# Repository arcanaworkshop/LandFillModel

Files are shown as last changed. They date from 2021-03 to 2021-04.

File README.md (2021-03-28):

# README Landfill Model Guide

Create by George Spearing for Arcana Workshop
March 2020

## Purpose

The lanfill model is run by an Arduino Nano with a breakout board to control audio track files. The audio track files live on the microSD card in the breakout board. Formmating for files are shown below.

## Audio Track Naming

The audio tracks are labeled using the scheme "TRACK000.wav" where "000" is the track identifier. These track numbers correspond to the buttons which light up specific sections.

## Track Numbering

- "000" Electric Power Plant
- "001" Empty - Not Used
- "002" Ground Water
- "003" Ground Liner
- "004" Leache Runoff
- "005" Gas Collection
- "006" Garbage Layer
- "007" Ground (Surface Layer)

## Track Formatting

The Arduino uses the TMRpcm library to play audio track from a microSD card. The full documentation for this library can be found at [https://github.com/TMRh20/TMRpcm/wiki](https://github.com/TMRh20/TMRpcm/wiki).

In summary, the tracks should be formatted as follows:

- Mono track
- 32000Hz (22050, 1600, 11025 also work)
- WAV, Unsigned 8 bit PCM

## Programming

I hope this doesn't need to be reprogrammed. There are two nano boards. 1 is the master and mainly controls all the leds. This is also the master to control the slave arduino file playing. The salve nano is a dedicated audio interpreter and player. This uses the micro SD card breakout. To program the slave nano, the SD car must NOT be connected. the MISO/MISI connections with the usbtiny during programming fail the upload. There is a switch on the circuit board that disables the SD card interface. Turn this off when progrmaming. DON'T FORGET TO TURN BACK ON ONCE DONE.

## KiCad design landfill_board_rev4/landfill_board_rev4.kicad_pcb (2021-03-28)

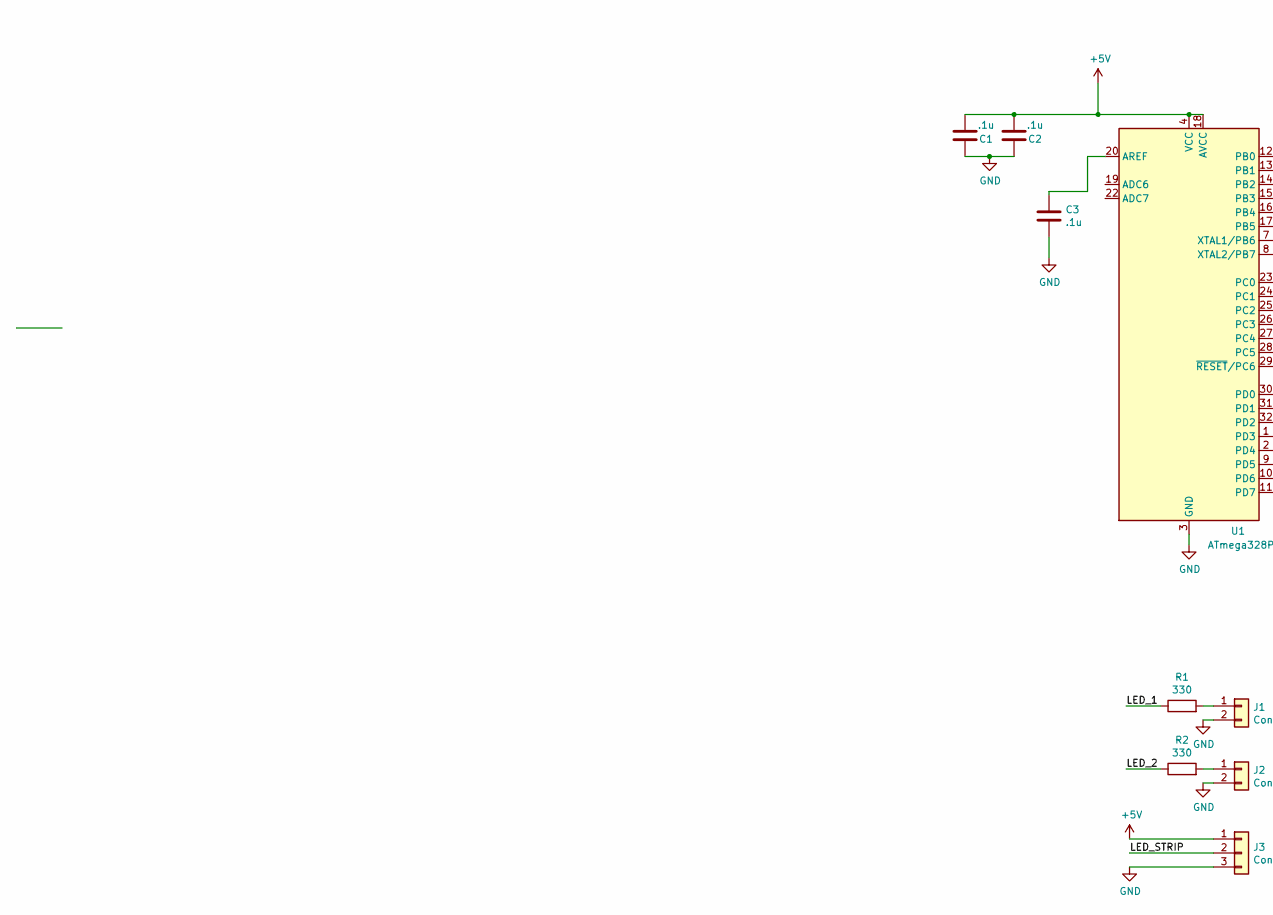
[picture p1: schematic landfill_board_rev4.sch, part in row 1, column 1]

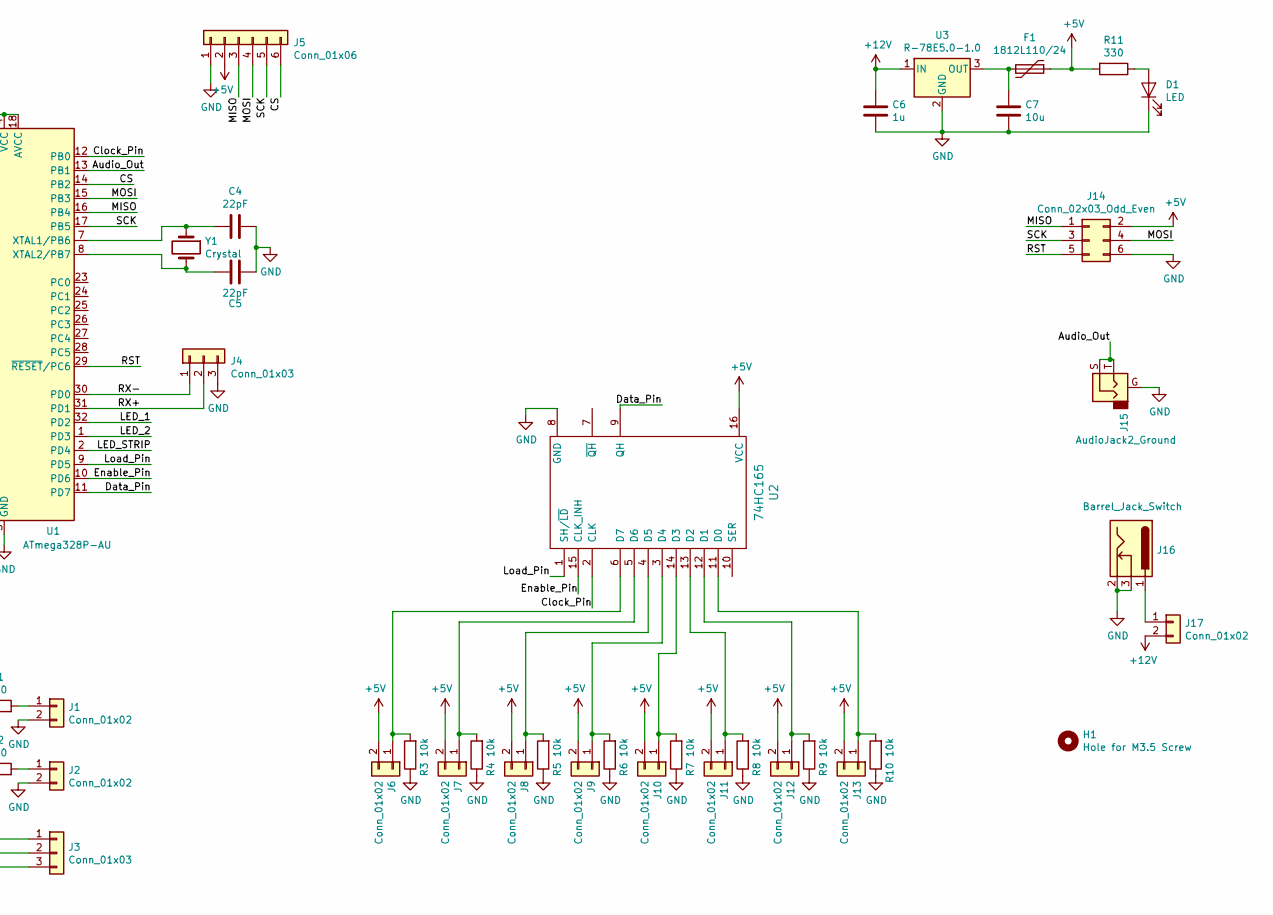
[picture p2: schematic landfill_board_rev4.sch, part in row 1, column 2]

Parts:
C1, C2, C3: .1u; C_0603_1608Metric_Pad1.05x0.95mm_HandSolder
C4, C5: 22pF; C_0603_1608Metric_Pad1.05x0.95mm_HandSolder
C6: 1u; C_0603_1608Metric_Pad1.05x0.95mm_HandSolder
C7: 10u; C_0603_1608Metric_Pad1.05x0.95mm_HandSolder
D1: LED; LED_0603_1608Metric_Pad1.05x0.95mm_HandSolder
F1: 1812L110/24; Fuse_1812_4532Metric_Pad1.30x3.40mm_HandSolder
H1: Hole for M3.5 Screw; MountingHole_3.5mm
J1, J2, J6, J7, J8, J9, J10, J11, J12, J13, J17: Conn_01x02; JST_PH_B2B-PH-K_1x02_P2.00mm_Vertical
J3: Conn_01x03; JST_PH_B3B-PH-K_1x03_P2.00mm_Vertical
J4: Conn_01x03; PinSocket_1x03_P2.54mm_Vertical
J5: Conn_01x06; PinHeader_1x06_P2.54mm_Vertical
J14: Conn_02x03_Odd_Even; PinHeader_2x03_P2.54mm_Vertical
J15: AudioJack2_Ground; Jack_3.5mm_CUI_SJ-3523-SMT_Horizontal
J16: Barrel_Jack_Switch; BarrelJack_CUI_PJ-036AH-SMT_Horizontal
R1, R2, R11: 330; R_0603_1608Metric_Pad1.05x0.95mm_HandSolder
R3, R4, R5, R6, R7, R8, R9, R10: 10k; R_0603_1608Metric_Pad1.05x0.95mm_HandSolder
U1: ATmega328P-AU; TQFP-32_7x7mm_P0.8mm
U2: 74HC165; SOIC-16_3.9x9.9mm_P1.27mm
U3: R-78E5.0-1.0; Converter_DCDC_RECOM_R-78E-0.5_THT
Y1: Crystal; Crystal_HC49-U_Vertical

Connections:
+5V: C1.2, C2.2, F1.1, J3.1, J5.2, J6.2, J7.2, J8.2, J9.2, J10.2, J11.2, J12.2, J13.2, J14.2, R11.2, U1.4 (VCC), U1.6 (VCC), U1.18 (AVCC), U2.16 (VCC)
+12V: C6.1, J17.2, U3.1 (IN)
/Audio_Out: J15.S, J15.T, U1.13 (PB1)
/CS: J5.6, U1.14 (PB2)
/Clock_Pin: U1.12 (PB0), U2.2 (CLK)
/Data_Pin: U1.11 (PD7), U2.9 (QH)
/Enable_Pin: U1.10 (PD6), U2.15 (CLK_INH)
/LED_1: R1.1, U1.32 (PD2)
/LED_2: R2.1, U1.1 (PD3)
/LED_STRIP: J3.2, U1.2 (PD4)
/Load_Pin: U1.9 (PD5), U2.1 (SH/~LD)
/MISO: J5.3, J14.1, U1.16 (PB4)
/MOSI: J5.4, J14.4, U1.15 (PB3)
/RST: J14.5, U1.29 (~RESET~/PC6)
/RX+: J4.2, U1.31 (PD1)
/RX-: J4.1, U1.30 (PD0)
/SCK: J5.5, J14.3, U1.17 (PB5)
GND: C1.1, C2.1, C3.2, C4.1, C5.1, C6.2, C7.2, D1.1 (K), J1.2, J2.2, J3.3, J4.3, J5.1, J14.6, J15.G, J16.2, J16.3, R3.1, R4.1, R5.1, R6.1, R7.1, R8.1, R9.1, R10.1, U1.3 (GND), U1.5 (GND), U1.21 (GND), U2.8 (GND), U3.2 (GND)
unnamed: C3.1, U1.20 (AREF)
unnamed: C4.2, U1.7 (XTAL1/PB6), Y1.1
unnamed: C5.2, U1.8 (XTAL2/PB7), Y1.2
unnamed: C7.1, F1.2, U3.3 (OUT)
unnamed: D1.2 (A), R11.1
unnamed: J1.1, R1.2
unnamed: J2.1, R2.2
unnamed: J6.1, R3.2, U2.6 (D7)
unnamed: J7.1, R4.2, U2.5 (D6)
unnamed: J8.1, R5.2, U2.4 (D5)
unnamed: J9.1, R6.2, U2.3 (D4)
unnamed: J10.1, R7.2, U2.14 (D3)
unnamed: J11.1, R8.2, U2.13 (D2)
unnamed: J12.1, R9.2, U2.12 (D1)
unnamed: J13.1, R10.2, U2.11 (D0)
unnamed: J16.1, J17.1

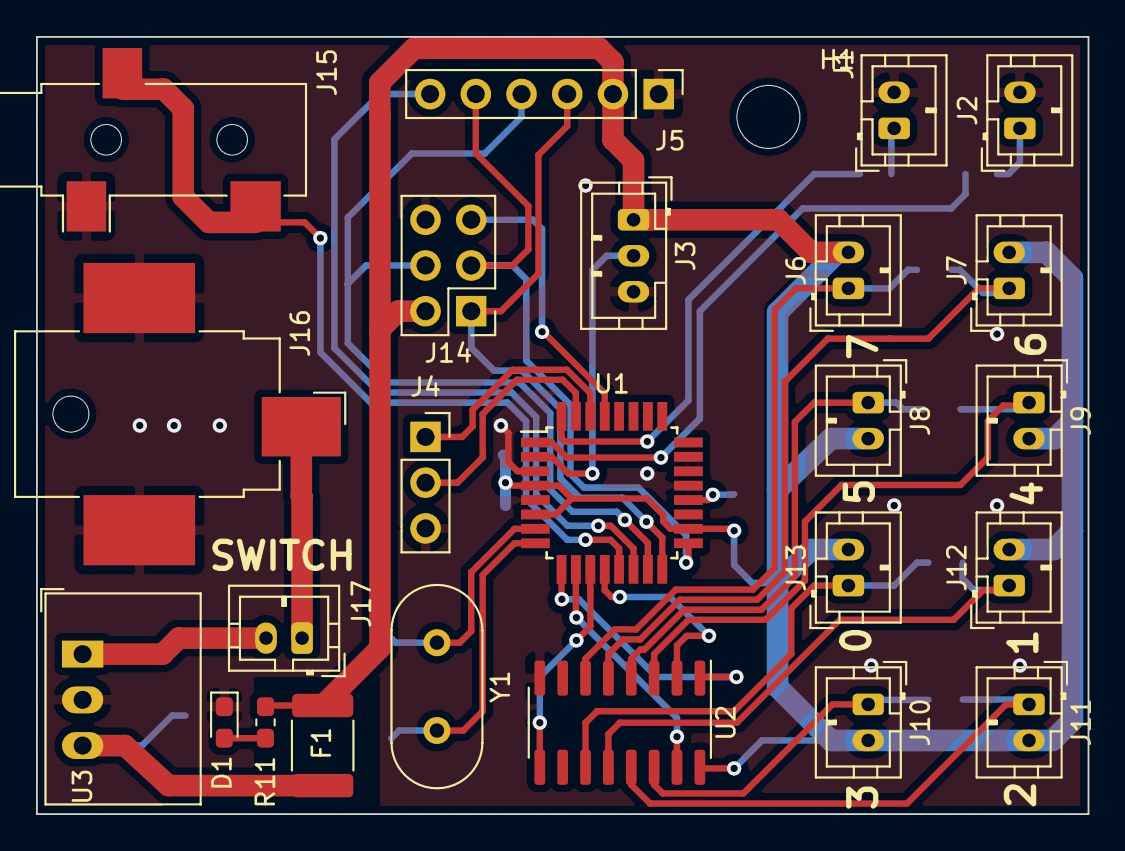
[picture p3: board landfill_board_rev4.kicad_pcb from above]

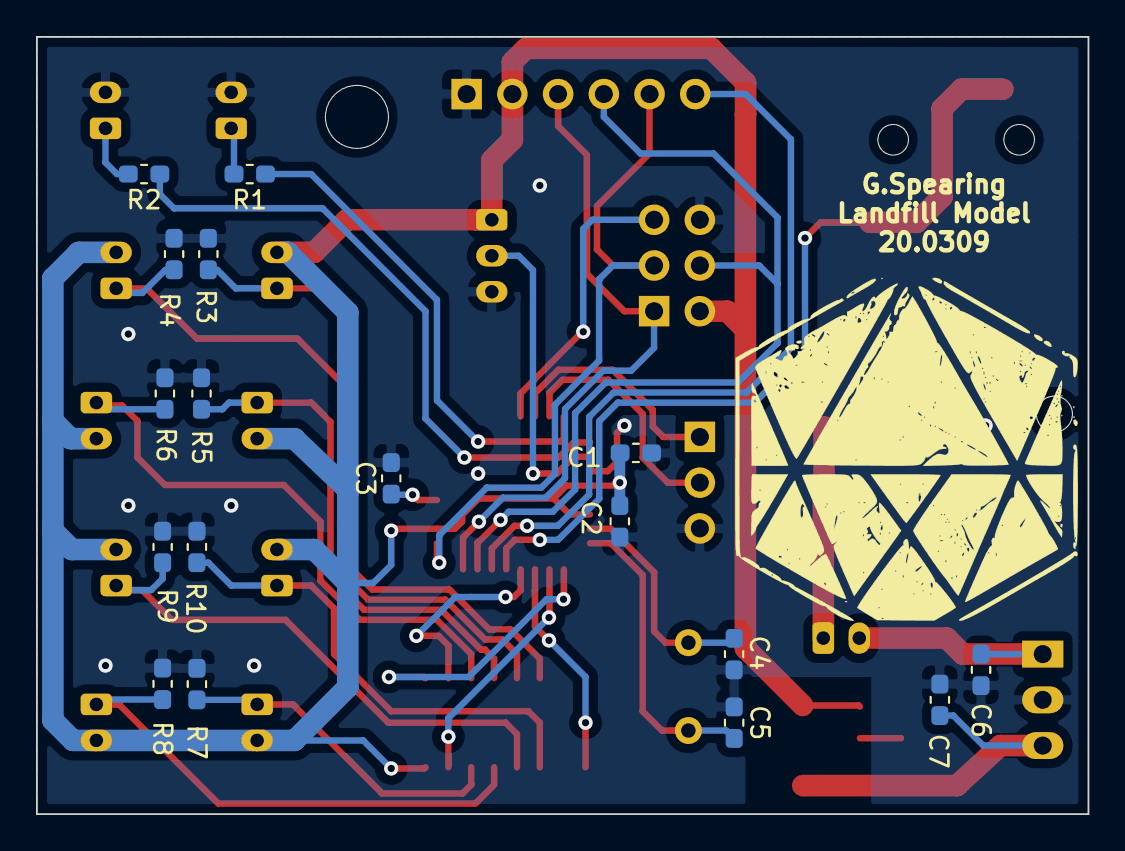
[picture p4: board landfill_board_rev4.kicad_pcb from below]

Board: 2 copper layers, 58.4 x 43.2 mm, 42 parts (17 on the bottom side), 34 nets.

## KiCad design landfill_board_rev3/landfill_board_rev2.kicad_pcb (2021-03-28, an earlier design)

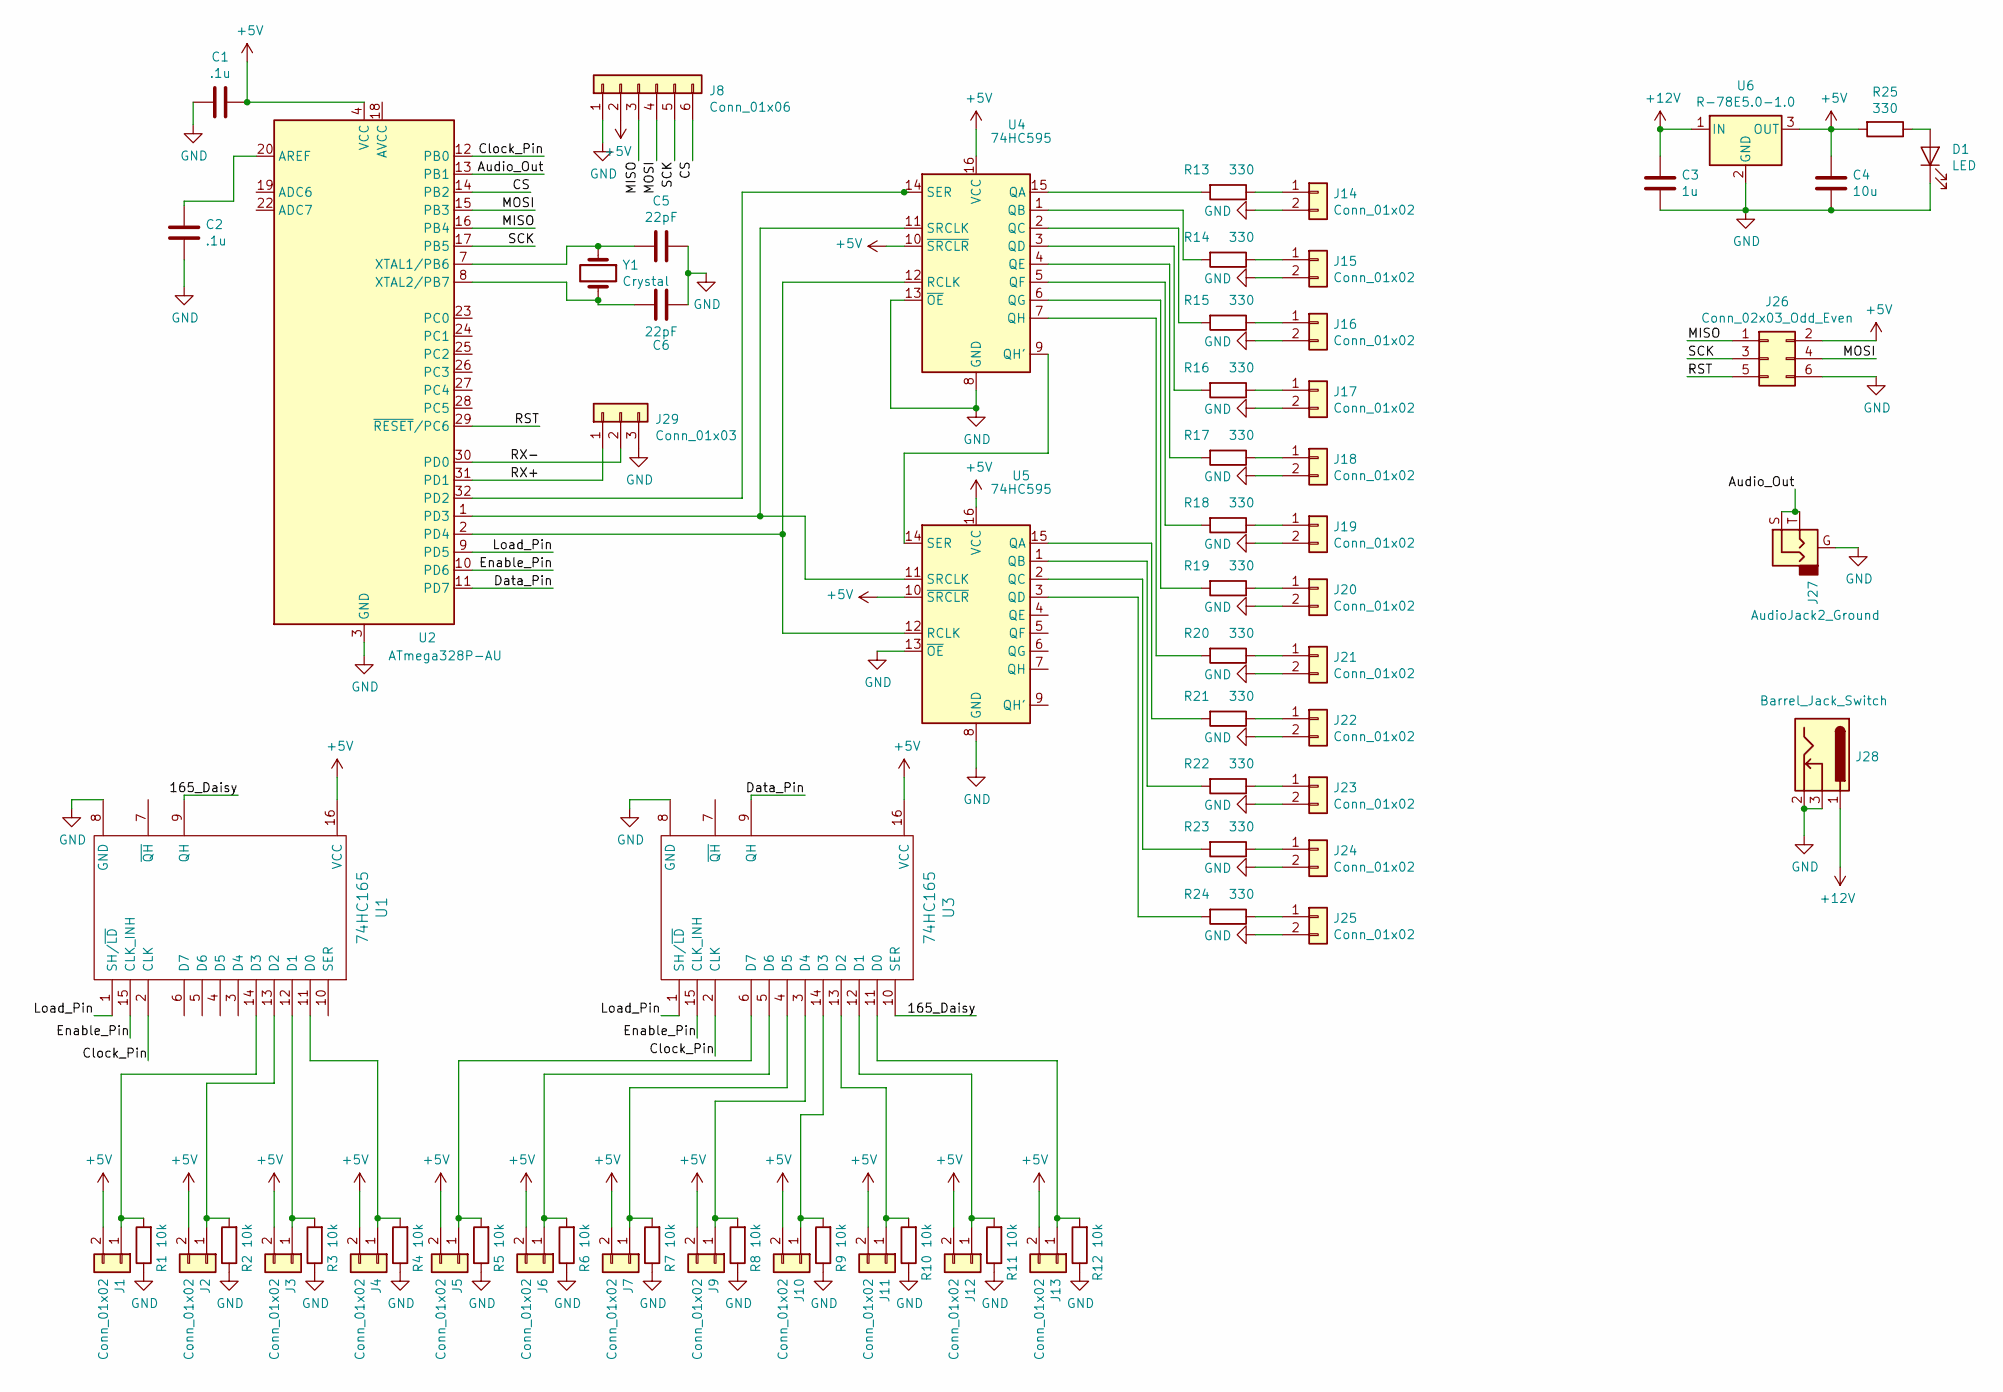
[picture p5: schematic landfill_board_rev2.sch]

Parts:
C1, C2: .1u; C_0603_1608Metric_Pad1.05x0.95mm_HandSolder
C3: 1u; C_0603_1608Metric_Pad1.05x0.95mm_HandSolder
C4: 10u; C_0603_1608Metric_Pad1.05x0.95mm_HandSolder
C5, C6: 22pF; C_0603_1608Metric_Pad1.05x0.95mm_HandSolder
D1: LED; LED_0603_1608Metric_Pad1.05x0.95mm_HandSolder
J1, J2, J3, J4, J5, J6, J7, J9, J10, J11, J12, J13, J14, J15, J16, J17, J18, J19, J20, J21, J22, J23, J24, J25: Conn_01x02; PinHeader_1x02_P2.00mm_Vertical
J8: Conn_01x06; PinHeader_1x06_P2.54mm_Vertical
J26: Conn_02x03_Odd_Even; PinHeader_2x03_P2.54mm_Vertical
J27: AudioJack2_Ground; Jack_3.5mm_CUI_SJ-3523-SMT_Horizontal
J28: Barrel_Jack_Switch; BarrelJack_CUI_PJ-036AH-SMT_Horizontal
J29: Conn_01x03; PinSocket_1x03_P2.54mm_Vertical
R1, R2, R3, R4, R5, R6, R7, R8, R9, R10, R11, R12: 10k; R_0603_1608Metric_Pad1.05x0.95mm_HandSolder
R13, R14, R15, R16, R17, R18, R19, R20, R21, R22, R23, R24, R25: 330; R_0603_1608Metric_Pad1.05x0.95mm_HandSolder
U1, U3: 74HC165; SOIC-16_3.9x9.9mm_P1.27mm
U2: ATmega328P-AU; TQFP-32_7x7mm_P0.8mm
U4, U5: 74HC595; SSOP-16_4.4x5.2mm_P0.65mm
U6: R-78E5.0-1.0; Converter_DCDC_RECOM_R-78E-0.5_THT
Y1: Crystal; Crystal_HC49-U_Vertical

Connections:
+5V: C1.1, C4.1, J1.2, J2.2, J3.2, J4.2, J5.2, J6.2, J7.2, J8.2, J9.2, J10.2, J11.2, J12.2, J13.2, J26.2, R25.2, U1.16 (VCC), U2.4 (VCC), U2.6 (VCC), U3.16 (VCC), U4.10 (~SRCLR), U4.16 (VCC), U5.10 (~SRCLR), U5.16 (VCC), U6.3 (OUT)
+12V: C3.1, J28.1, U6.1 (IN)
/165_Daisy: U1.9 (QH), U3.10 (SER)
/Audio_Out: J27.S, J27.T, U2.13 (PB1)
/CS: J8.6, U2.14 (PB2)
/Clock_Pin: U1.2 (CLK), U2.12 (PB0), U3.2 (CLK)
/Data_Pin: U2.11 (PD7), U3.9 (QH)
/Enable_Pin: U1.15 (CLK_INH), U2.10 (PD6), U3.15 (CLK_INH)
/Load_Pin: U1.1 (SH/~LD), U2.9 (PD5), U3.1 (SH/~LD)
/MISO: J8.3, J26.1, U2.16 (PB4)
/MOSI: J8.4, J26.4, U2.15 (PB3)
/RST: J26.5, U2.29 (~RESET~/PC6)
/RX+: J29.1, U2.31 (PD1)
/RX-: J29.2, U2.30 (PD0)
/SCK: J8.5, J26.3, U2.17 (PB5)
GND: C1.2, C2.2, C3.2, C4.2, C5.1, C6.1, D1.1 (K), J8.1, J14.2, J15.2, J16.2, J17.2, J18.2, J19.2, J20.2, J21.2, J22.2, J23.2, J24.2, J25.2, J26.6, J27.G, J28.2, J28.3, J29.3, R1.1, R2.1, R3.1, R4.1, R5.1, R6.1, R7.1, R8.1, R9.1, R10.1, R11.1, R12.1, U1.8 (GND), U2.3 (GND), U2.5 (GND), U2.21 (GND), U3.8 (GND), U4.8 (GND), U4.13 (~OE), U5.8 (GND), U5.13 (~OE), U6.2 (GND)
unnamed: C2.1, U2.20 (AREF)
unnamed: C5.2, U2.7 (XTAL1/PB6), Y1.1
unnamed: C6.2, U2.8 (XTAL2/PB7), Y1.2
unnamed: D1.2 (A), R25.1
unnamed: J1.1, R1.2, U1.14 (D3)
unnamed: J2.1, R2.2, U1.13 (D2)
unnamed: J3.1, R3.2, U1.12 (D1)
unnamed: J4.1, R4.2, U1.11 (D0)
unnamed: J5.1, R5.2, U3.6 (D7)
unnamed: J6.1, R6.2, U3.5 (D6)
unnamed: J7.1, R7.2, U3.4 (D5)
unnamed: J9.1, R8.2, U3.3 (D4)
unnamed: J10.1, R9.2, U3.14 (D3)
unnamed: J11.1, R10.2, U3.13 (D2)
unnamed: J12.1, R11.2, U3.12 (D1)
unnamed: J13.1, R12.2, U3.11 (D0)
unnamed: J14.1, R13.1
unnamed: J15.1, R14.1
unnamed: J16.1, R15.1
unnamed: J17.1, R16.1
unnamed: J18.1, R17.1
unnamed: J19.1, R18.1
unnamed: J20.1, R19.1
unnamed: J21.1, R20.1
unnamed: J22.1, R21.1
unnamed: J23.1, R22.1
unnamed: J24.1, R23.1
unnamed: J25.1, R24.1
unnamed: R13.2, U4.15 (QA)
unnamed: R14.2, U4.1 (QB)
unnamed: R15.2, U4.2 (QC)
unnamed: R16.2, U4.3 (QD)
unnamed: R17.2, U4.4 (QE)
unnamed: R18.2, U4.5 (QF)
unnamed: R19.2, U4.6 (QG)
unnamed: R20.2, U4.7 (QH)
unnamed: R21.2, U5.15 (QA)
unnamed: R22.2, U5.1 (QB)
unnamed: R23.2, U5.2 (QC)
unnamed: R24.2, U5.3 (QD)
unnamed: U2.1 (PD3), U4.11 (SRCLK), U5.11 (SRCLK)
unnamed: U2.2 (PD4), U4.12 (RCLK), U5.12 (RCLK)
unnamed: U2.32 (PD2), U4.14 (SER)
unnamed: U4.9 (QH'), U5.14 (SER)

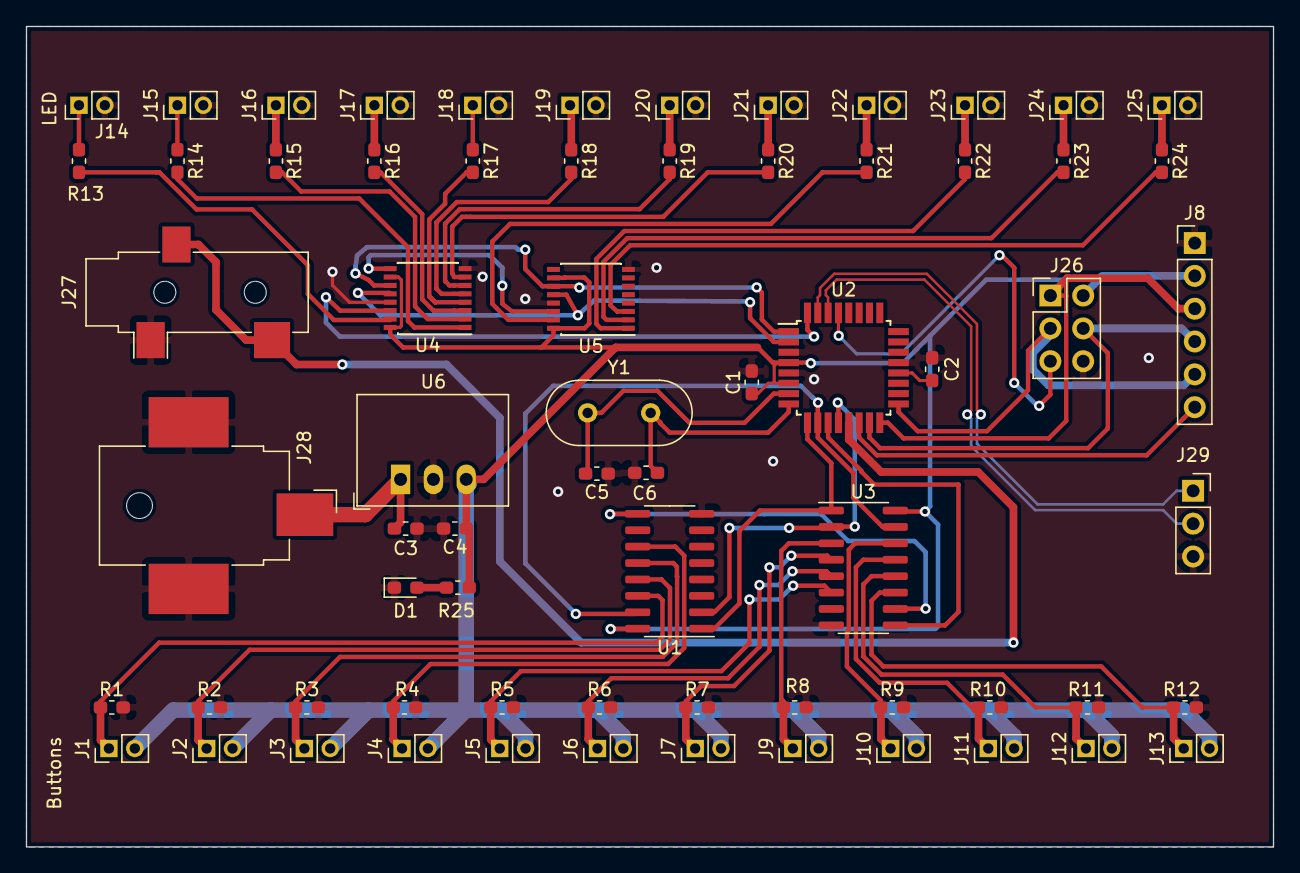
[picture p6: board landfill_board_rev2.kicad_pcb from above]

Board: 2 copper layers, 96.5 x 63.5 mm, 68 parts (0 on the bottom side), 60 nets.

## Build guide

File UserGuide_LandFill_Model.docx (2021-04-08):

# Landfill Model User Guide

# Description

There are 7 buttons paired with 7 audio tracks. When a user presses a button, a section of lights will show on the display accompanied by an audio file. Once the audio track ends, the lights will also turn off. One light, representing the methane gas flame, will always be lit when the model is powered.

The landfill model is run by two Arduino Nano with one controlling lights and one controlling audio. A speaker amplifier is provided for audio output. The audio track files live on the microSD card in the breakout board with the second Arduino Nano. The audio files on the SD card can be replaced. See sections below for more information on track naming and formatting.

Volume adjustment is done via the speaker amplifier.

# Audio Track Information

The audio tracks are labeled using the scheme “TRACK000.wav” where “000” is the track identifier. These track numbers correspond to the buttons which light up specific sections. If new audio tracks are loaded onto the SD card, Arduino Board 1 will need to be reprogrammed to include the audio file lengths. See “Programming” for more information. The default track lengths are listed below.

Track Number Description Default Time (sec)

“000” Electric Power Plant 22

~~“~~~~001” Empty - Not Used~~

“002” Ground Water 20

“003” Ground Liner 22

“004” Leachate Runoff 26

“005” Gas Collection 22

“006” Garbage Layer 14

“007” Ground (Surface Layer) 26

## Track Formatting

The Arduino uses the TMRpcm library to play audio track from a microSD card. The full documentation for this library can be found at https:/github.com/TMRh20/TMRpcm/wiki.

In summary, the tracks should be formatted as follows:

Mono track

32000Hz (22050, 1600, 11025 also work)

WAV, Unsigned 8 bit PCM

# Troubleshooting

Model won’t turn on

There are two power cords needed to power the model. Ensure both are plugged in. Additionally, there is a power switch for the electronics boards located near Arduino Board 1. Ensure this switch is on.

No Audio When Pressing Buttons

Check the volume control. There is a volume knob on the speaker amplifier near Arduino Board 1. Additionally, there is a small switch on the Arduino Board 2 that controls power to the SD card. Ensure the switch is enabled.

No Lights When Pressing Buttons

Ensure the LED Lights are connected to power. There are multiple wires that flow through the model to provide power and data. Ensure these wires are in working condition.

# Programming

Code located at https://github.com/arcanaworkshop

There are two Arduino Nano boards. Board 1 is the master and mainly controls all the Leds and Button Input. Board 1 is the master to control the slave Arduino (Board 2) which controls audio playback. Board 2 uses the micro SD card breakout board. To program Board 2, the SD car must NOT be connected to the board. The MISO/MISI connections with the usbtiny during programming will cause the program upload to fail. There is a switch on the circuit board that disables the SD card interface. Turn this off when programming. Once programming is done, turn the switch back on. Otherwise, no audio files will play during operation.

LandFill User Guide 2

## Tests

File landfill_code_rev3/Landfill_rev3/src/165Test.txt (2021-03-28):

/*
 * SN74HC165N_shift_reg
 *
 * Program to shift in the bit values from a SN74HC165N 8-bit
 * parallel-in/serial-out shift register.
 *
 * This sketch demonstrates reading in 16 digital states from a
 * pair of daisy-chained SN74HC165N shift registers while using
 * only 4 digital pins on the Arduino.
 *
 * You can daisy-chain these chips by connecting the serial-out
 * (Q7 pin) on one shift register to the serial-in (Ds pin) of
 * the other.
 * 
 * Of course you can daisy chain as many as you like while still
 * using only 4 Arduino pins (though you would have to process
 * them 4 at a time into separate unsigned long variables).
 * 
*/

#include <Arduino.h>

/* How many shift register chips are daisy-chained.
*/
#define NUMBER_OF_SHIFT_CHIPS   1

/* Width of data (how many ext lines).
*/
#define DATA_WIDTH   NUMBER_OF_SHIFT_CHIPS * 8

/* Width of pulse to trigger the shift register to read and latch.
*/
#define PULSE_WIDTH_USEC   5

/* Optional delay between shift register reads.
*/
#define POLL_DELAY_MSEC   1

/* You will need to change the "int" to "long" If the
 * NUMBER_OF_SHIFT_CHIPS is higher than 2.
*/
#define BYTES_VAL_T unsigned int

int ploadPin        = 5;  // Connects to Parallel load pin the 165
int clockEnablePin  = 6;  // Connects to Clock Enable pin the 165
int dataPin         = 7; // Connects to the Q7 pin the 165
int clockPin        = 8; // Connects to the Clock pin the 165

BYTES_VAL_T pinValues;
BYTES_VAL_T oldPinValues;

/* This function is essentially a "shift-in" routine reading the
 * serial Data from the shift register chips and representing
 * the state of those pins in an unsigned integer (or long).
*/
BYTES_VAL_T read_shift_regs()
{
    long bitVal;
    BYTES_VAL_T bytesVal = 0;

    /* Trigger a parallel Load to latch the state of the data lines,
    */
    digitalWrite(clockEnablePin, HIGH);
    digitalWrite(ploadPin, LOW);
    delayMicroseconds(PULSE_WIDTH_USEC);
    digitalWrite(ploadPin, HIGH);
    digitalWrite(clockEnablePin, LOW);

    /* Loop to read each bit value from the serial out line
     * of the SN74HC165N.
    */
    for(int i = 0; i < DATA_WIDTH; i++)
    {
        bitVal = digitalRead(dataPin);

        /* Set the corresponding bit in bytesVal.
        */
        bytesVal |= (bitVal << ((DATA_WIDTH-1) - i));

        /* Pulse the Clock (rising edge shifts the next bit).
        */
        digitalWrite(clockPin, HIGH);
        delayMicroseconds(PULSE_WIDTH_USEC);
        digitalWrite(clockPin, LOW);
    }

    return(bytesVal);
}

/* Dump the list of zones along with their current status.
*/
void display_pin_values()
{
    Serial.print("Pin States:\r\n");

    for(int i = 0; i < DATA_WIDTH; i++)
    {
        Serial.print("  Pin-");
        Serial.print(i);
        Serial.print(": ");

        if((pinValues >> i) & 1)
            Serial.print("HIGH");
        else
            Serial.print("LOW");

        Serial.print("\r\n");
    }

    Serial.print("\r\n");
}

void setup()
{
    Serial.begin(9600);

    /* Initialize our digital pins...
    */
    pinMode(ploadPin, OUTPUT);
    pinMode(clockEnablePin, OUTPUT);
    pinMode(clockPin, OUTPUT);
    pinMode(dataPin, INPUT);

    digitalWrite(clockPin, LOW);
    digitalWrite(ploadPin, HIGH);

    /* Read in and display the pin states at startup.
    */
    pinValues = read_shift_regs();
    display_pin_values();
    oldPinValues = pinValues;
}

void loop()
{
    /* Read the state of all zones.
    */
    pinValues = read_shift_regs();

    /* If there was a chage in state, display which ones changed.
    */
    if(pinValues != oldPinValues)
    {
        Serial.print("*Pin value change detected*\r\n");
        display_pin_values();
        oldPinValues = pinValues;
    }

    delay(POLL_DELAY_MSEC);
}

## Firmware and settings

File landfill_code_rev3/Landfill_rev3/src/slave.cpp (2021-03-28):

/**
 * George Spearing
 * Revision 3 of Landfill Model Code
 * 8 Buttons for user input. Play one audio file and light
 * up one section of the model. One LED always lit
 * February 26, 2020
 */

// #define DEBUG

#include <Arduino.h>
#include <Wire.h>

#include <SD.h>                      // need to include the SD library
#include <TMRpcm.h>           //  also need to include this library...
#include <SPI.h>
#define SD_ChipSelectPin 10  //using digital pin 4 on arduino nano 328, can use other pins

TMRpcm tmrpcm;   // create an object for use in this sketch

void receiveEvent(int howMany);

void setup(){

    Wire.begin(1);
    Wire.onReceive(receiveEvent);
    #ifdef DEBUG
        Serial.begin(9600);
    #endif

    // start tmrpcm
    tmrpcm.speakerPin = 9; // define speaker pin
    tmrpcm.setVolume(3); // volume setting for audio file
    tmrpcm.quality(0); // SET TO QUALITY 0 FOR BEST AUDIO
    tmrpcm.disable();

    #ifndef DEBUG
    SD.begin(SD_ChipSelectPin);
    #endif

    // test and start SD Card
    #ifdef DEBUG
        if(SD.begin(SD_ChipSelectPin)){
            Serial.println("SD OK");
            tmrpcm.play("TRACK000.wav");
        }
        else{
            Serial.println("SD FAIL");
        }
    #endif
}

void loop(){

}

void receiveEvent(int howMany){
    while(Wire.available()){
        char inByte = Wire.read();
        switch(inByte){
            case 'a':
                tmrpcm.play("TRACK000.wav");
                #ifdef DEBUG
                    if(tmrpcm.isPlaying()){
                        Serial.println("playing audio");
                    }
                #endif
                break;
            case 'b':
                tmrpcm.play("TRACK001.wav");
                #ifdef DEBUG
                    if(tmrpcm.isPlaying()){
                        Serial.println("playing audio");
                    }
                #endif
                break;
            case 'c':
                tmrpcm.play("TRACK002.wav");
                #ifdef DEBUG
                    if(tmrpcm.isPlaying()){
                        Serial.println("playing audio");
                    }
                #endif
                break;
            case 'd':
                tmrpcm.play("TRACK003.wav");
                #ifdef DEBUG
                    if(tmrpcm.isPlaying()){
                        Serial.println("playing audio");
                    }
                #endif
                break;
            case 'e':
                tmrpcm.play("TRACK004.wav");
                #ifdef DEBUG
                    if(tmrpcm.isPlaying()){
                        Serial.println("playing audio");
                    }
                #endif
                break;
            case 'f':
                tmrpcm.play("TRACK005.wav");
                #ifdef DEBUG
                    if(tmrpcm.isPlaying()){
                        Serial.println("playing audio");
                    }
                #endif
                break;
            case 'g':
                tmrpcm.play("TRACK006.wav");
                #ifdef DEBUG
                    if(tmrpcm.isPlaying()){
                        Serial.println("playing audio");
                    }
                #endif
                break;
            case 'h':
                tmrpcm.play("TRACK007.wav");
                #ifdef DEBUG
                    if(tmrpcm.isPlaying()){
                        Serial.println("playing audio");
                    }
                #endif
                break;
            case 'z':
                tmrpcm.stopPlayback();
                #ifdef DEBUG
                    if(tmrpcm.isPlaying()){
                        Serial.println("playing audio");
                    }
                #endif
                break;
        }
    }
}

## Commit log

2021-03-28 initial commit code revision 0
    [landfill_board_rev0.kicad_pcb, landfill_board_rev0.sch]
2021-03-28 redesign board and code
    [landfill_board_rev1-2019-12-19-20-02-00.sch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]
2021-03-28 cleanup functionality
    [landfill_board_rev2-B_Cu.gbr, landfill_board_rev2-B_Mask.gbr, landfill_board_rev2-B_Paste.gbr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]
2021-03-28 add sound functionality
    [landfill_board_rev4-B_Cu.gbr, landfill_board_rev4-B_Mask.gbr, landfill_board_rev4-B_Paste.gbr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]
